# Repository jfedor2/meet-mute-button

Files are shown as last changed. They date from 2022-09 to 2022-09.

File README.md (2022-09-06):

# Mute button/status indicator for Google Meet

This is a USB mute button/call status indicator for Google Meet. It has LEDs that light up when you join a meeting and turn red when your mic is muted. Here's a [blog post](https://workspaceupdates.googleblog.com/2022/08/google-meet-call-control-usb-peripheral-devices.html) from Google that introduces the concept and shows how to configure the device in Google Meet settings.

And here's [a video](https://www.youtube.com/watch?v=Z7VTwXMVH2g) showing the device in action.

It uses the following components:

* Raspberry Pi Pico
* either a 12x or 16x WS2812 LED ring, depending on which size you want (available on AliExpress)
* Kailh low-profile (choc v1) mechanical keyboard switch
* [3D-printed parts](3d-printed-parts) (print in white so that the LEDs shine through)
* M3x4 flat head and M2x4 screws

Wire the DI pad on the LED ring to GPIO2 on the Pico and the keyboard switch to GPIO3 and GND. Also wire 5V and GND pads on the ring to VBUS and GND on the Pico.

To flash the Pico with the firmware, hold the BOOTSEL button while connecting it to the computer and copy the [mute\_button.uf2](mute_button.uf2) file to the drive that shows up.

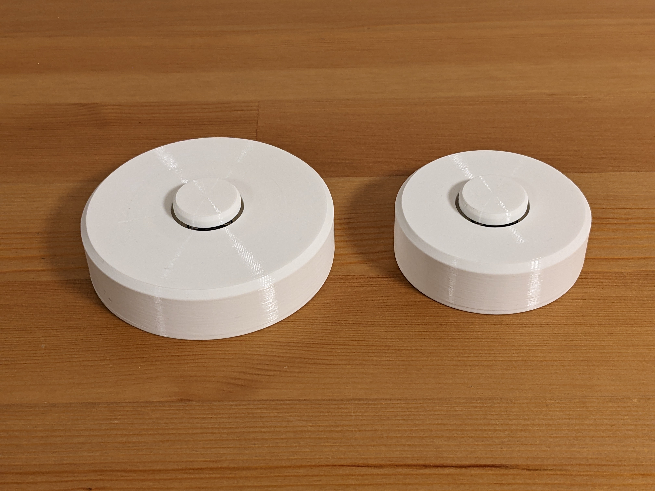
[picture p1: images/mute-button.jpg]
Mute buttons

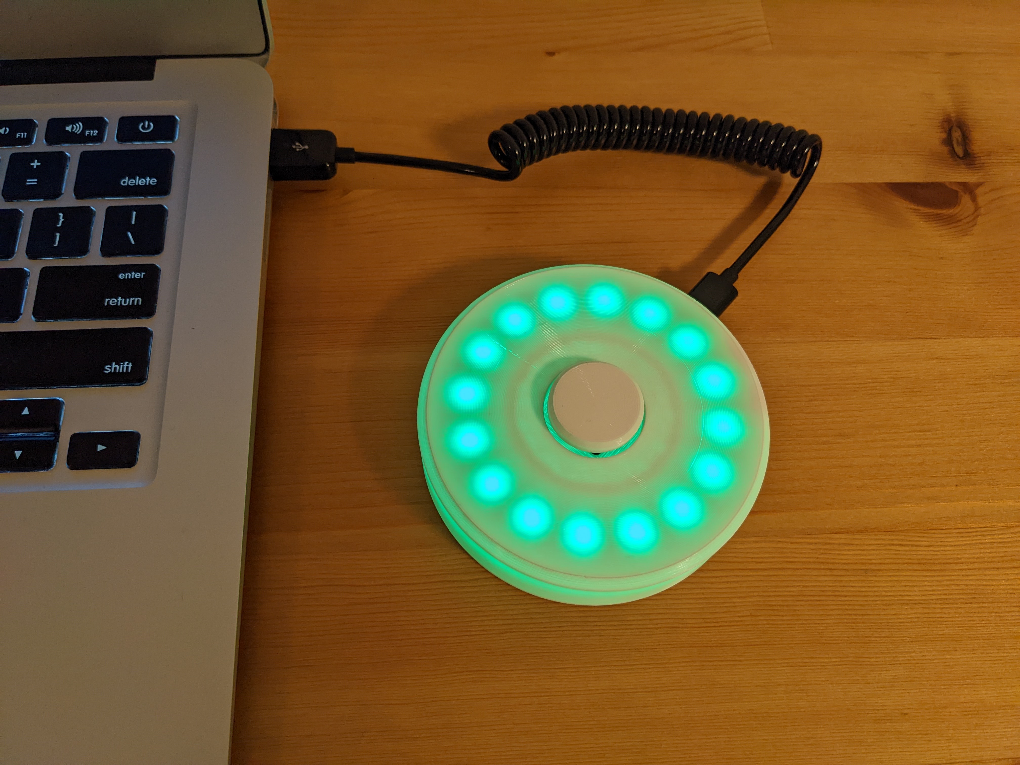
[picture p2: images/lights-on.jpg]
Mute button with lights on

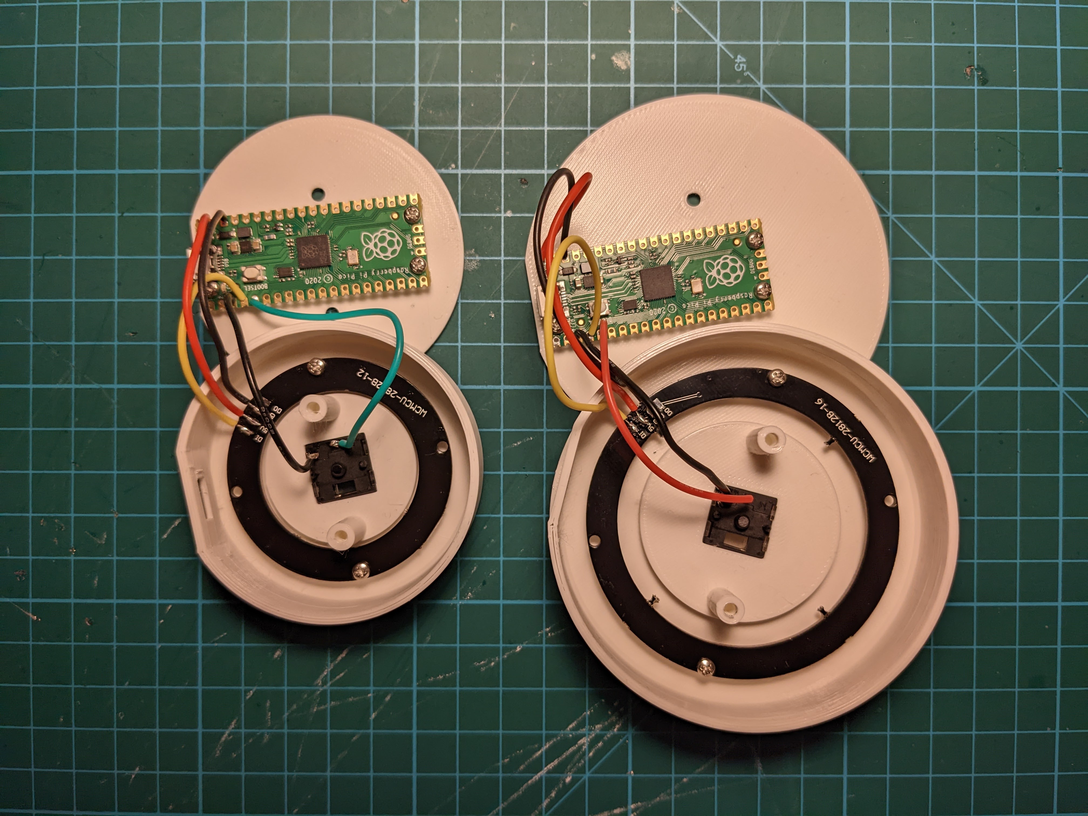
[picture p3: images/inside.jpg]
Wiring inside the case


## How to compile the code

```
git clone https://github.com/jfedor2/meet-mute-button.git
cd meet-mute-button
git submodule update --init
cd code
mkdir build
cd build
cmake ..
make
```

## Acknowledgements

`ws2812.cc` and `ws2818.pio` files are derived from [Pico SDK examples](https://github.com/raspberrypi/pico-examples). They come with the following license:

```
Copyright 2020 (c) 2020 Raspberry Pi (Trading) Ltd.

Redistribution and use in source and binary forms, with or without modification, are permitted provided that the
following conditions are met:

1. Redistributions of source code must retain the above copyright notice, this list of conditions and the following
   disclaimer.

2. Redistributions in binary form must reproduce the above copyright notice, this list of conditions and the following
   disclaimer in the documentation and/or other materials provided with the distribution.

3. Neither the name of the copyright holder nor the names of its contributors may be used to endorse or promote products
   derived from this software without specific prior written permission.

THIS SOFTWARE IS PROVIDED BY THE COPYRIGHT HOLDERS AND CONTRIBUTORS "AS IS" AND ANY EXPRESS OR IMPLIED WARRANTIES,
INCLUDING, BUT NOT LIMITED TO, THE IMPLIED WARRANTIES OF MERCHANTABILITY AND FITNESS FOR A PARTICULAR PURPOSE ARE
DISCLAIMED. IN NO EVENT SHALL THE COPYRIGHT HOLDER OR CONTRIBUTORS BE LIABLE FOR ANY DIRECT, INDIRECT, INCIDENTAL,
SPECIAL, EXEMPLARY, OR CONSEQUENTIAL DAMAGES (INCLUDING, BUT NOT LIMITED TO, PROCUREMENT OF SUBSTITUTE GOODS OR
SERVICES; LOSS OF USE, DATA, OR PROFITS; OR BUSINESS INTERRUPTION) HOWEVER CAUSED AND ON ANY THEORY OF LIABILITY,
WHETHER IN CONTRACT, STRICT LIABILITY, OR TORT (INCLUDING NEGLIGENCE OR OTHERWISE) ARISING IN ANY WAY OUT OF THE USE OF
THIS SOFTWARE, EVEN IF ADVISED OF THE POSSIBILITY OF SUCH DAMAGE.
```

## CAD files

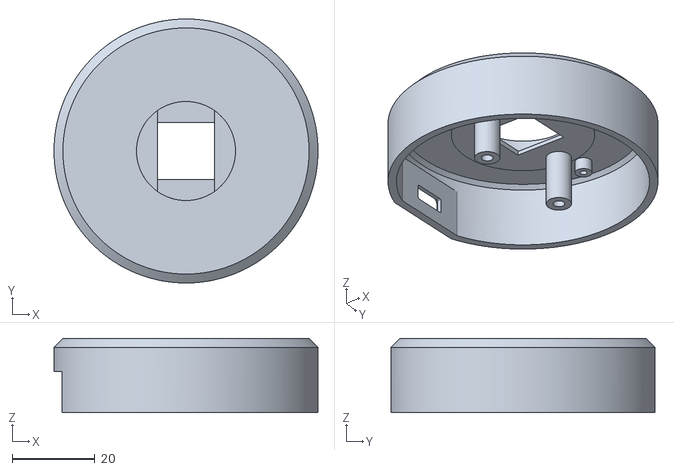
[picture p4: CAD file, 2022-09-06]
3d-printed-parts/MeetMuteButton12Top.stl
64.0 x 64.0 x 18.0

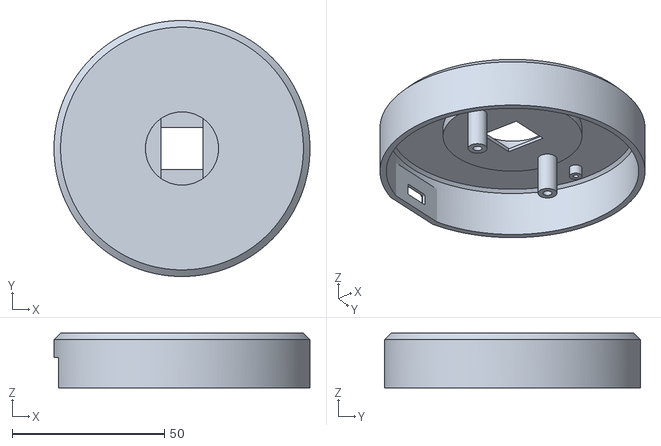
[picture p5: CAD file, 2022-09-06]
3d-printed-parts/MeetMuteButton16Top.stl
84.0 x 84.0 x 18.0

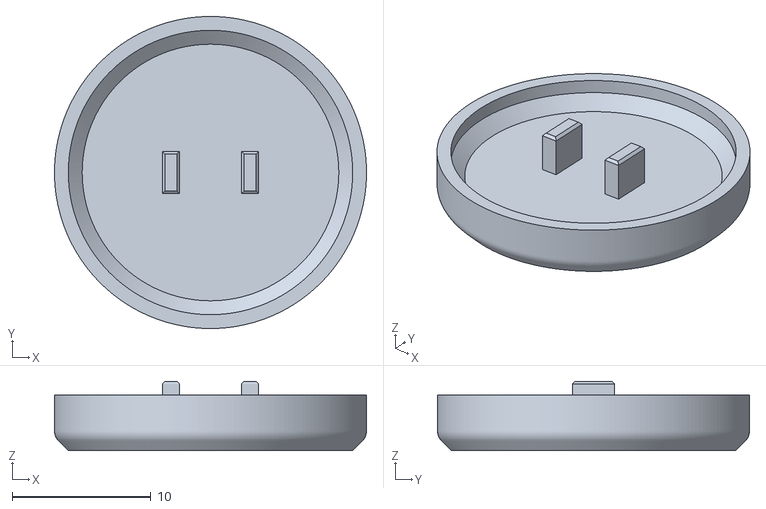
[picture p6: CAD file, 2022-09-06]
3d-printed-parts/KailhButtoncap.stl
22.5 x 22.5 x 5.00

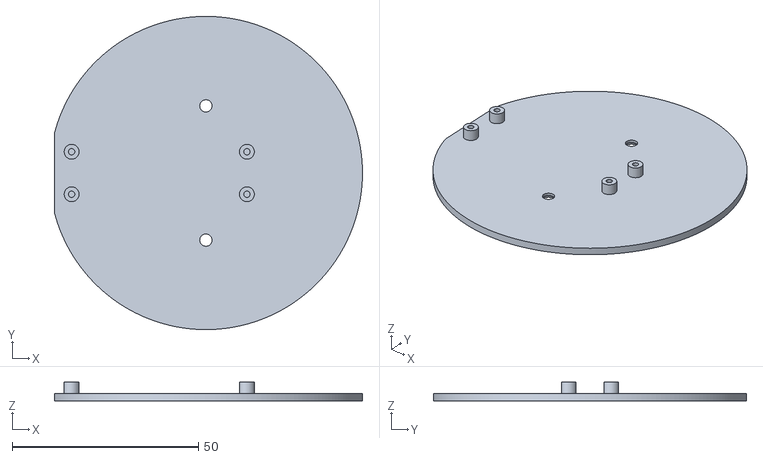
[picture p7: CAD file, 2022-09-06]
3d-printed-parts/MeetMuteButton16Bottom.stl
82.6 x 84.0 x 5.00

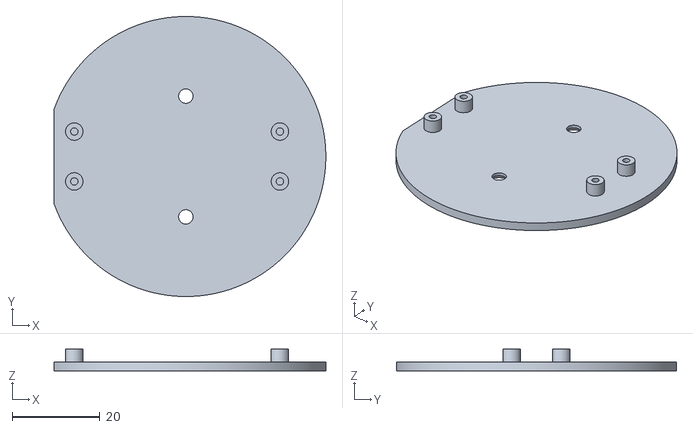
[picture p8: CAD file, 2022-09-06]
3d-printed-parts/MeetMuteButton12Bottom.stl
62.1 x 64.0 x 5.00

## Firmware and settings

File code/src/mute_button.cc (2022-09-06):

#include <bsp/board.h>
#include <tusb.h>

#include <hardware/gpio.h>
#include <pico/bootrom.h>

#include "our_descriptor.h"
#include "ws2812.h"

#define BUTTON_PIN 3
#define NUM_PIXELS 16

#define RED 0x004000
#define GREEN 0x400000

bool mute_state = false;
bool oncall_state = false;

void update_led() {
    uint32_t color = 0x000000;
    if (oncall_state) {
        if (mute_state) {
            color = RED;
        } else {
            color = GREEN;
        }
    }

    for (int i = 0; i < NUM_PIXELS; i++) {
        put_pixel(color);
    }
}

int main() {
    board_init();
    tusb_init();
    neopixel_init();

    gpio_init(BUTTON_PIN);
    gpio_set_dir(BUTTON_PIN, GPIO_IN);
    gpio_pull_up(BUTTON_PIN);

/*
    sleep_ms(10);
    if (!gpio_get(BUTTON_PIN)) {
        reset_usb_boot(0, 0);
    }
*/

    update_led();

    uint8_t report;

    bool prev_button_state = false;
    absolute_time_t pressed_at = nil_time;

    while (true) {
        tud_task();
        if (!tud_hid_ready()) {
            continue;
        }

        bool button_state = !gpio_get(BUTTON_PIN);
        if (button_state && !prev_button_state) {
            report = !mute_state;
            tud_hid_report(REPORT_ID, &report, 1);
            pressed_at = get_absolute_time();
        }

        if (!button_state && prev_button_state) {
            if (!mute_state && (absolute_time_diff_us(pressed_at, get_absolute_time()) > 500000)) {
                report = 1;
                tud_hid_report(REPORT_ID, &report, 1);
            }
        }

        prev_button_state = button_state;
        sleep_ms(4);
    }

    return 0;
}

void tud_hid_set_report_cb(uint8_t itf, uint8_t report_id, hid_report_type_t report_type, uint8_t const* buffer, uint16_t bufsize) {
    if (bufsize >= 1) {
        oncall_state = buffer[0] & 0x01;
        mute_state = buffer[0] & 0x02;
        update_led();
    }
}

uint16_t tud_hid_get_report_cb(uint8_t itf, uint8_t report_id, hid_report_type_t report_type, uint8_t* buffer, uint16_t reqlen) {
    return 0;
}
